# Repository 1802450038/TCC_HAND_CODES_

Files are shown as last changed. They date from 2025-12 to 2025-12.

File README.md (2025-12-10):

# Prótese Mioelétrica de Mão (TCC)

Este repositório contém os códigos fonte e documentação para o desenvolvimento de uma prótese de mão mioelétrica de baixo custo. O projeto combina modelagem 3D baseada em projetos open-source consagrados com um sistema de controle eletrônico customizado dividido em dois módulos via comunicação sem fio.

## 📋 Sobre o Projeto

O objetivo deste projeto é capturar sinais musculares (EMG) do usuário e transformá-los em movimentos precisos de abertura e fechamento da mão robótica. O sistema foi projetado para ser modular, separando a aquisição de dados do controle dos motores.

### Arquitetura do Sistema

O projeto é dividido em duas partes principais que se comunicam via protocolo **ESP-NOW**:

1. **EMG Box (Transmissor):** Responsável pela leitura dos sinais musculares e interface com o usuário.
2. **Controlador da Mão (Receptor):** Responsável por receber os comandos e acionar os servomotores da prótese.

## 🛠️ Hardware e Eletrônica

### 1. EMG Box (Processamento e Interface)

Este módulo é o "cérebro" de aquisição. Ele lê o sensor muscular, processa o sinal para decidir entre os estados de **Mão Aberta** ou **Mão Fechada** e envia o comando via WiFi.

* **Microcontrolador:** ESP32 DevKit V1
* **Funcionalidades:**
  * Leitura do sensor EMG.
  * **Menu Interativo:** Conta com um display OLED/LCD (verificar tipo no código) que permite ao usuário configurar parâmetros de sensibilidade e visualizar o status do sistema em tempo real.
  * Envio de pacotes via ESP-NOW.

### 2. Controlador da Mão (Atuadores)

Este módulo fica embarcado na própria estrutura da mão ou antebraço, recebendo os sinais e movendo os dedos.

* **Microcontrolador:** ESP32-C3 SuperMini (pelo seu tamanho reduzido e eficiência).
* **Funcionalidades:**
  * Recepção de comandos via ESP-NOW.
  * Controle PWM dos servomotores (via I2C ou direto, conforme implementação `esp32_i2cservo`).

### ⚡ Diagrama Elétrico

O esquema de ligação detalhado para ambos os módulos pode ser visualizado abaixo:

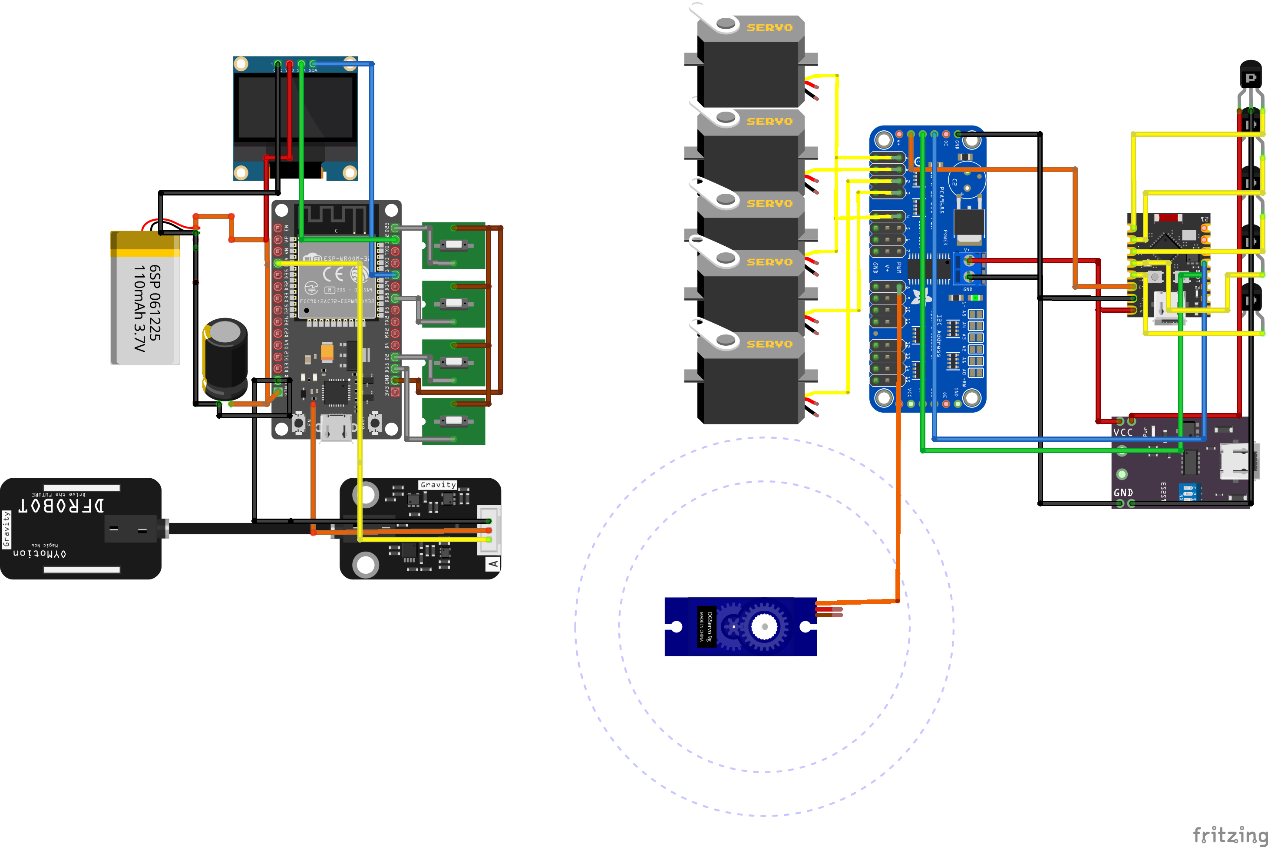
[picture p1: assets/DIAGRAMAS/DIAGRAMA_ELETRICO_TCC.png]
Diagrama Elétrico


## 🖨️ Design Mecânico e Peças 3D

A estrutura mecânica é uma hibridização de projetos renomados com adaptações personalizadas para acomodar a eletrônica e melhorar a funcionalidade.

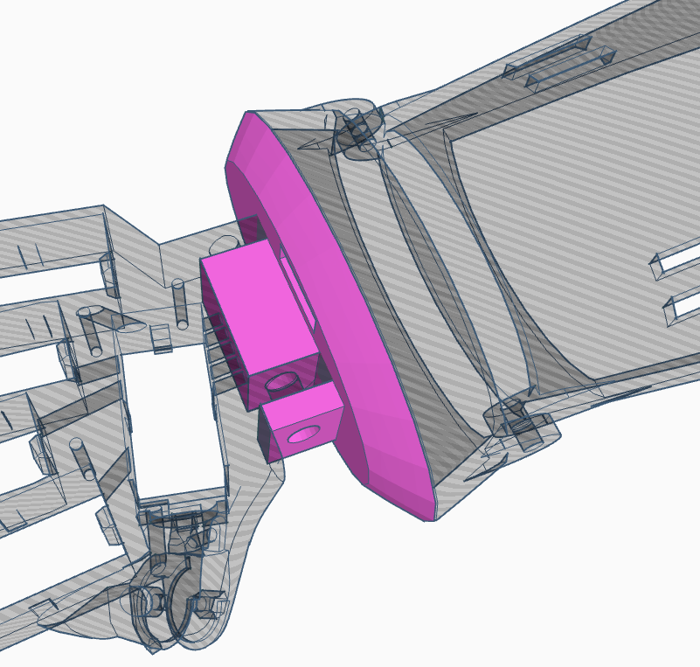
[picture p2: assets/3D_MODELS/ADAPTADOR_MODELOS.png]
Adaptador_modelos Adaptador Modelos


Ponteiras modificadas Ponteiras macias modificadasCaixa do sensor EMG Caixa sensor emg

### Referências Base

* **InMoov Hand:** A base do design dos dedos e palma. [Visite o projeto oficial](https://inmoov.fr/inmoov-hand/).
* **Capobussi Design:** Utilizado como referência para mecanismos e adaptações do antebraço. [Ver no Thingiverse](https://www.thingiverse.com/thing:3771283).

### 🌟 Peças Customizadas

Para tornar este projeto viável com o hardware escolhido (especialmente o ESP32-C3 SuperMini e o sistema de baterias), foram modeladas peças exclusivas:

* *Adaptador para união dos modelos 3D.*
* Ponteiras modifcadas para material flexivel.
* Caixa para acomodar o sensor emg juntamente do controlador, botões e tela.
* *As peças customizadas estão disponíveis na pasta `assets/3D_Models` deste repositório.*

## 📡 Comunicação (ESP-NOW)

A comunicação entre a **EMG Box** e a **Mão** utiliza o protocolo **ESP-NOW** da Espressif. Isso garante:

* Baixa latência (resposta rápida aos movimentos musculares).
* Conexão direta sem necessidade de roteador WiFi.
* Baixo consumo de energia.

O `EMG_BOX` atua como **Controller (Master)**, enviando a decisão de movimento, enquanto o `ESP32_C3` atua como **Peripheral (Slave)**, executando a ação motora.

## 🚀 Como Utilizar

1. **Upload dos Códigos:**
   * Carregue o código da pasta `EMG_BOX` no ESP32 DevKit V1.
   * Carregue o código da pasta ESP32_I2CServo no ESP32-C3 SuperMini.
   * *Nota: Certifique-se de atualizar o endereço MAC do receptor no código do transmissor.*
2. **Calibração:**
   * Ligue a EMG Box.
   * Utilize o **Menu no Display** para ajustar o limiar (threshold) do sensor EMG conforme a força muscular do usuário.
3. **Operação:**
   * Ao contrair o músculo, o sistema detectará o pico de sinal e enviará o comando de fechar/abrir a mão.

## 📂 Estrutura de Arquivos

```bash
├── EMG_BOX/              # Código fonte para o ESP32 DevKit V1
├── ESP32_I2CServo/         # Código fonte para o ESP32-C3 SuperMini
├── assets/3D_Models/            # Arquivos STL (Customizados e Modificados)
├── assets/DIAGRAMAS                 # Diagramas elétricos e documentação
└── README.md
```

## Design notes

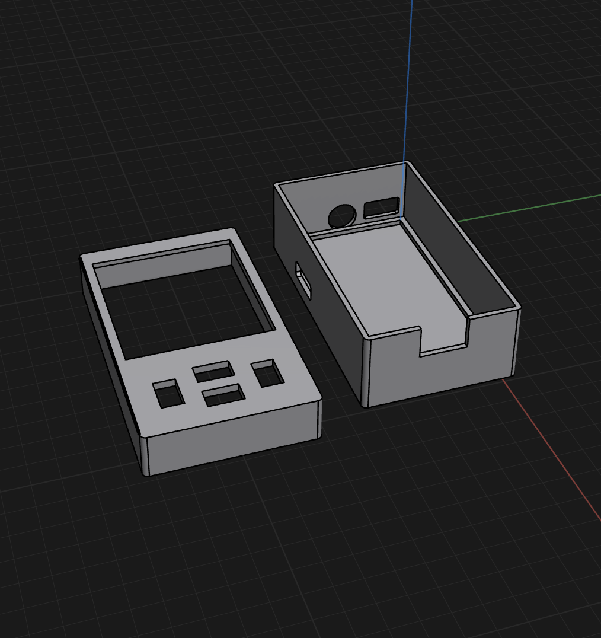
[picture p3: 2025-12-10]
assets/3D_MODELS/EMG_BOX.png

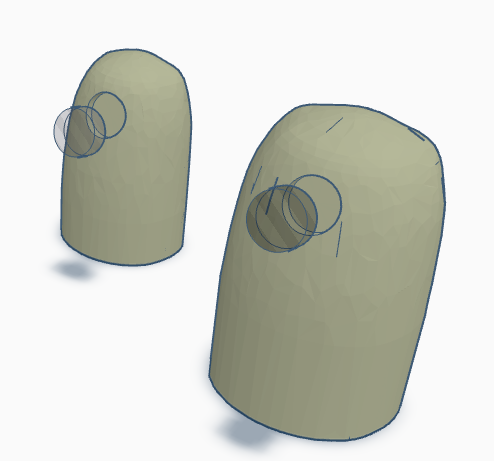
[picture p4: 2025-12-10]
assets/3D_MODELS/PONTEIRA_MODIFICADA.png

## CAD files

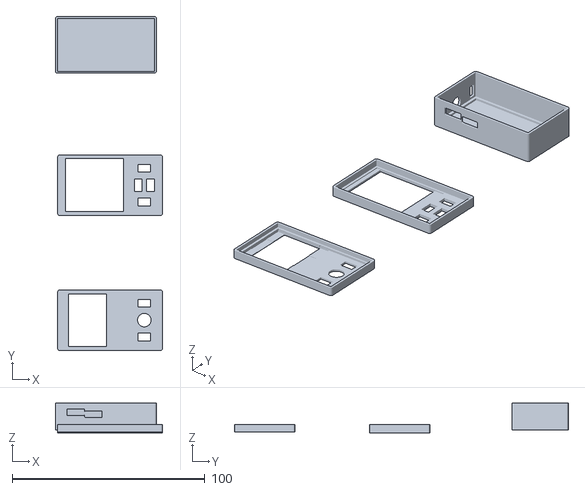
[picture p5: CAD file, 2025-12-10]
assets/3D_MODELS/EMG_BOX2mm.stl
55.6 x 173.2 x 15.5

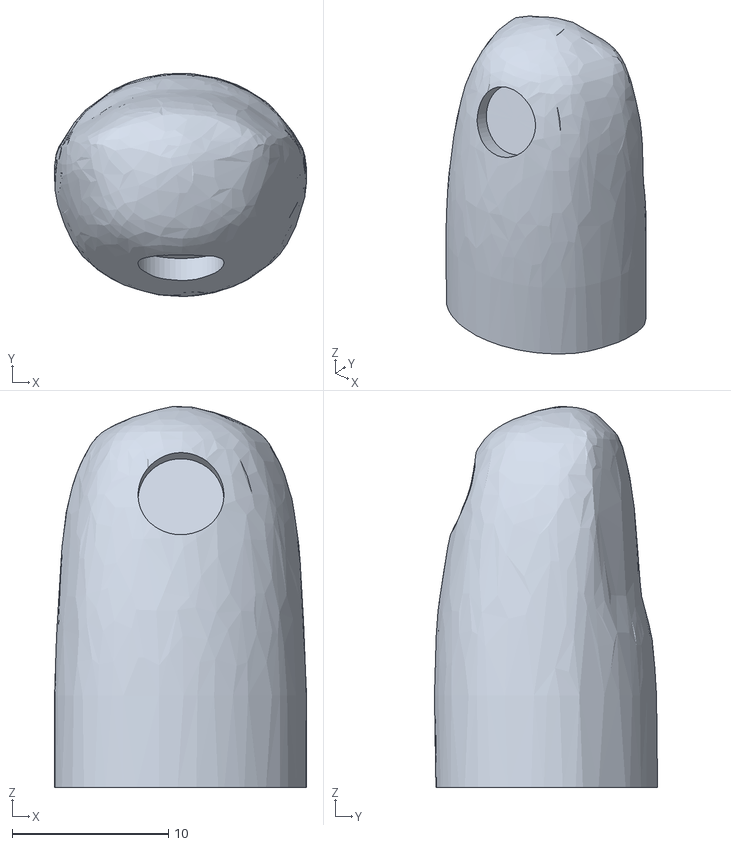
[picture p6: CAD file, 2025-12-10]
assets/3D_MODELS/TIP_THUMB.stl
16.1 x 14.3 x 24.4

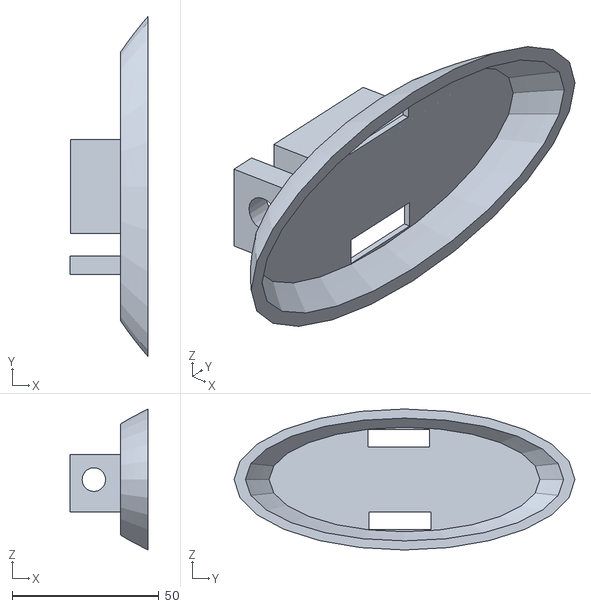
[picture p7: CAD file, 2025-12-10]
assets/3D_MODELS/JOINT_HAND.stl
26.7 x 116.0 x 48.0

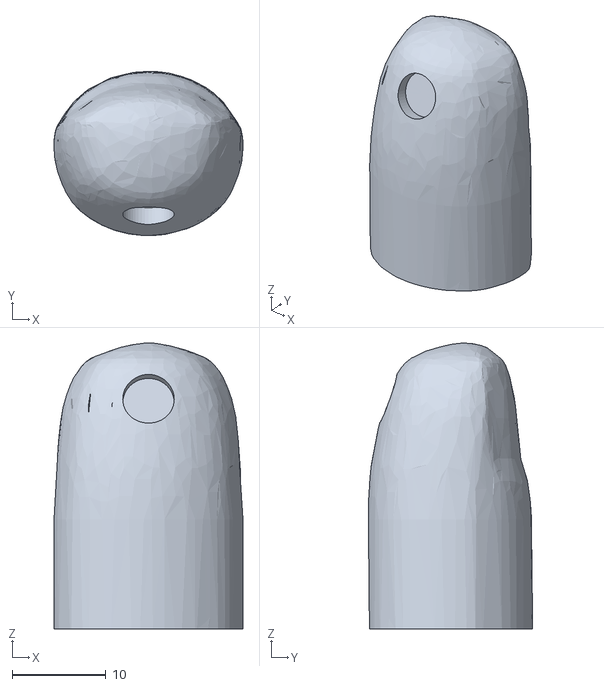
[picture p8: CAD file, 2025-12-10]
assets/3D_MODELS/TIP_FINGER.stl
20.2 x 17.6 x 30.6

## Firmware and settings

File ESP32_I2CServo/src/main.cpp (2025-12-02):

#include <Arduino.h>
#include <Wire.h>
#include "display.h"
#include "buttons.h"
#include "motors.h"
#include "hall.h"
#include <WiFi.h>
#include <esp_now.h>
#include <esp_wifi.h>
#include "smoothFilter.h" // Inclua a classe que criamos acima

#define OLED_ENABLE FALSE

// --- DEFINIÇÃO DOS PINOS E LIMITES ---
#define PIN_THUMB A4
#define PIN_INDEX A3
#define PIN_MIDDLE A2
#define PIN_RING A1
#define PIN_LITTLE A0

int THRESHOLD_THUMB = 2230;
int THRESHOLD_INDEX = 2320;
int THRESHOLD_MIDDLE = 0;
int THRESHOLD_RING = 2330;
int THRESHOLD_LITTLE = 2250;
// Instanciando os filtros (Apenas Pinos)
SmoothFilter filterThumb(PIN_THUMB);
SmoothFilter filterIndex(PIN_INDEX);
SmoothFilter filterMiddle(PIN_MIDDLE);
SmoothFilter filterRing(PIN_RING);
SmoothFilter filterLittle(PIN_LITTLE);

struct RawData
{
  int thumbVal;
  int indexVal;
  int middleVal;
  int ringVal;
  int littleVal;
};

RawData sharedData;          // Dados compartilhados
SemaphoreHandle_t dataMutex; // Cadeado de segurança

void readSensorsTask(void *parameter)
{
  for (;;)
  {
    // 1. Lê os valores suavizados (Isso leva alguns microssegundos)
    int t = filterThumb.read();
    int i = filterIndex.read();
    int m = filterMiddle.read();
    int r = filterRing.read();
    int l = filterLittle.read();

    // 2. Tenta pegar o cadeado para salvar na variável global
    if (xSemaphoreTake(dataMutex, (TickType_t)10) == pdTRUE)
    {
      sharedData.thumbVal = t;
      sharedData.indexVal = i;
      sharedData.middleVal = m;
      sharedData.ringVal = r;
      sharedData.littleVal = l;

      xSemaphoreGive(dataMutex); // Libera o cadeado IMEDIATAMENTE
    }

    // 3. Dorme por 10ms. Isso define a taxa de atualização (100Hz)
    // Essencial para o ESP32 não travar o Watchdog
    vTaskDelay(pdMS_TO_TICKS(10));
  }
}

int inc_thumb_pos = 0;
int inc_index_pos = 0;
int inc_middle_pos = 0;
int inc_ring_pos = 0;
int inc_little_pos = 0;
int inc_gesture = 0;
int inc_action_mode = 0;
bool inc_hand_state = false;
bool inc_feedback = false;
int inc_threshold_thumb = THRESHOLD_THUMB;
int inc_threshold_index = THRESHOLD_INDEX;
int inc_threshold_middle = THRESHOLD_MIDDLE;
int inc_threshold_ring = THRESHOLD_RING;
int inc_threshold_little = THRESHOLD_LITTLE;

typedef struct struct_inc_message
{
  int thumb_pos;
  int index_pos;
  int middle_pos;
  int ring_pos;
  int little_pos;
  int gesture;
  int action_mode;
  bool hand_state;
  bool feedback;
  int inc_threshold_thumb;
  int inc_threshold_index;
  int inc_threshold_middle;
  int inc_threshold_ring;
  int inc_threshold_little;
} struct_inc_message;

typedef struct struct_out_message
{
  int thumb_hall;
  int index_hall;
  int middle_hall;
  int ring_hall;
  int little_hall;
} struct_out_message;

String success;
struct_out_message OUT_DATA;
struct_inc_message INC_DATA;

esp_now_peer_info_t peerInfo;
uint8_t broadcastAddress[] = {0xe0, 0x5a, 0x1b, 0xa1, 0x33, 0x44};

void readMacAddress()
{
  uint8_t baseMac[6];
  esp_err_t ret = esp_wifi_get_mac(WIFI_IF_STA, baseMac);
  if (ret == ESP_OK)
  {
    Serial.printf("%02x:%02x:%02x:%02x:%02x:%02x\n",
                  baseMac[0], baseMac[1], baseMac[2],
                  baseMac[3], baseMac[4], baseMac[5]);
  }
  else
  {
    Serial.println("Failed to read MAC address");
  }
}
// Callback when data is sent
void OnDataSent(const uint8_t *mac_addr, esp_now_send_status_t status)
{
  Serial.print("\r\nLast Packet Send Status:\t");
  Serial.println(status == ESP_NOW_SEND_SUCCESS ? "Delivery Success" : "Delivery Fail");
  if (status == 0)
  {
    success = "Delivery Success :)";
  }
  else
  {
    success = "Delivery Fail :(";
  }
}
// Callback when data is received
void OnDataRecv(const uint8_t *mac, const uint8_t *incomingData, int len)
{
  memcpy(&INC_DATA, incomingData, sizeof(INC_DATA));
  inc_thumb_pos = INC_DATA.thumb_pos;
  inc_index_pos = INC_DATA.index_pos;
  inc_middle_pos = INC_DATA.middle_pos;
  inc_ring_pos = INC_DATA.ring_pos;
  inc_little_pos = INC_DATA.little_pos;
  inc_gesture = INC_DATA.gesture;
  inc_action_mode = INC_DATA.action_mode;
  inc_hand_state = INC_DATA.hand_state;
  inc_feedback = INC_DATA.feedback;
  inc_threshold_thumb = INC_DATA.inc_threshold_thumb;
  inc_threshold_index = INC_DATA.inc_threshold_index;
  inc_threshold_middle = INC_DATA.inc_threshold_middle;
  inc_threshold_ring = INC_DATA.inc_threshold_ring;
  inc_threshold_little = INC_DATA.inc_threshold_little;
}

void updateThresholds()
{
  THRESHOLD_THUMB = inc_threshold_thumb;
  THRESHOLD_INDEX = inc_threshold_index;
  THRESHOLD_MIDDLE = inc_threshold_middle;
  THRESHOLD_RING = inc_threshold_ring;
  THRESHOLD_LITTLE = inc_threshold_little;
}
// 1205 3425
void prepareDataToSend()
{
  OUT_DATA.thumb_hall = analogRead(HALL_SENSOR_PIN_THUMB);
  OUT_DATA.index_hall = analogRead(HALL_SENSOR_PIN_INDEX);
  OUT_DATA.middle_hall = analogRead(HALL_SENSOR_PIN_MIDDLE);
  OUT_DATA.ring_hall = analogRead(HALL_SENSOR_PIN_RING);
  OUT_DATA.little_hall = analogRead(HALL_SENSOR_PIN_LITTLE);
}

void setupNow()
{
  WiFi.mode(WIFI_STA);
  if (esp_now_init() != ESP_OK)
  {
    Serial.println("Error initializing ESP-NOW");
    return;
  }

  esp_now_register_recv_cb(esp_now_recv_cb_t(OnDataRecv));
}

void setup()
{
  // initServoFeedBack();

  initHallSensor();
  Serial.begin(115200); // Initialize serial communication
  delay(1000);
  Serial.println("Initializing");
  analogReadResolution(12);
  initPCA9685();
  // delay(500);
  // closeHand();
  delay(1000);
  openHand();
  delay(1000);
  Serial.println("Setup HALL");
  setupNow();
  dataMutex = xSemaphoreCreateMutex();
  xTaskCreate(
      readSensorsTask,
      "ReadSensors",
      4096,
      NULL,
      1,
      NULL);

  Serial.println("Sistema Iniciado com FreeRTOS Estavel.");
  delay(500);
}

bool isPressed(int val, int threshold)
{
  return (val < threshold);
}

void action_mode()
{
  switch (inc_action_mode)
  {
  case 0:
    Serial.println("Modo EMG");
    toogleHandState(inc_hand_state);
    break;
  case 1:
    Serial.println("Modo angulo");
    movServoByAngle(0, inc_thumb_pos);
    movServoByAngle(1, inc_index_pos);
    movServoByAngle(2, inc_middle_pos);
    movServoByAngle(3, inc_ring_pos);
    movServoByAngle(4, inc_little_pos);
    break;
  case 2:
    toggleGestureHand(inc_gesture);
    break;
  case 3:
    Serial.print("Modo Touch");

  case 4:
    Serial.print("Modo Toggle");
    toogleHandState(inc_hand_state);
  }
}

String getActionModeName(int action)
{
  if (action == 0)
  {
    return String("EMG - MODE");
  }
  else if (action == 1)
  {
    return String("ANGLE - MODE");
  }
  else if (action == 2)
  {
    return String("GESTURE - MODE");
  }
  else if (action == 3)
  {
    return String("TOGGLE - MODE");
  }
  else if (action == 4)
  {
    return String("DEBUG - MODE");
  }
  return "ERROR NOT DEFINED: " + String(action);
}

// // Display Functions
void updateValues(int freqMillis)
{
  static unsigned long lastSendTime = 0;

  if (millis() - lastSendTime >= freqMillis)
  {
    action_mode();
    // prepareDataToSend();
    updateThresholds();
    Serial.println("Thumb pos: " + String(inc_thumb_pos));
    Serial.println("Index pos: " + String(inc_index_pos));
    Serial.println("Middle pos: " + String(inc_middle_pos));
    Serial.println("Ring pos: " + String(inc_ring_pos));
    Serial.println("Little pos: " + String(inc_little_pos));
    Serial.println("Gesture : " + String(inc_gesture));
    Serial.println("Action mode: " + String(inc_action_mode) + " " + getActionModeName(inc_action_mode));
    Serial.println("Hand state: " + String(inc_hand_state));
    Serial.println("Feedback: " + String(inc_feedback));
    Serial.println("Thumb_threshold: " + String(THRESHOLD_THUMB));
    Serial.println("Index_threshold: " + String(THRESHOLD_INDEX));
    Serial.println("Middle_threshold: " + String(THRESHOLD_MIDDLE));
    Serial.println("Ring_threshold: " + String(THRESHOLD_RING));
    Serial.println("Little_threshold: " + String(THRESHOLD_LITTLE));
    lastSendTime = millis();
  }
}

void debugHallValues()
{
  Serial.print(OUT_DATA.thumb_hall);
  Serial.print(",");
  Serial.print(OUT_DATA.index_hall);
  Serial.print(",");
  Serial.print(OUT_DATA.middle_hall);
  Serial.print(",");
  Serial.print(OUT_DATA.ring_hall);
  Serial.print(",");
  Serial.println(OUT_DATA.little_hall);
}

void debugServo()
{
  for (size_t i = 0; i < 180; i++)
  {
    movServoByAngle(8, i);
    Serial.println("Angle: " + String(i));
    delay(300);
  }
}
void debugThresholds(bool validValues, RawData currentValues)
{
  if (validValues)
  {
    Serial.print("T:");
    Serial.print(":");
    Serial.print(THRESHOLD_THUMB);
    Serial.print(":");
    Serial.print(HALL_SENSOR_PIN_THUMB_THRESHOLD);
    Serial.print(":");
    Serial.print(currentValues.thumbVal);
    Serial.print(isPressed(currentValues.thumbVal, THRESHOLD_THUMB) ? "(ON) " : "(of) ");

    Serial.print("I:");
    Serial.print(currentValues.indexVal);
    Serial.print(isPressed(currentValues.indexVal, THRESHOLD_INDEX) ? "(ON) " : "(of) ");

    Serial.print("M:");
    Serial.print(currentValues.middleVal);
    Serial.print(isPressed(currentValues.middleVal, THRESHOLD_MIDDLE) ? "(ON) " : "(of) ");
    Serial.print("R:");
    Serial.print(currentValues.ringVal);
    Serial.print(isPressed(currentValues.ringVal, THRESHOLD_RING) ? "(ON) " : "(of) ");

    Serial.print("L:");
    Serial.print(currentValues.littleVal);
    Serial.println(isPressed(currentValues.littleVal, THRESHOLD_LITTLE) ? "(ON)" : "(of)");
  }
}

void loop()
{

  // readMacAddress();
  // debugServo();

  updateValues(300);

  RawData currentReads;
  bool dadosValidos = false;

  // // 1. Pega os dados da Task de forma segura
  if (xSemaphoreTake(dataMutex, (TickType_t)100) == pdTRUE)
  {
    currentReads = sharedData; // Copia rápida
    dadosValidos = true;
    xSemaphoreGive(dataMutex);
  }

  if (dadosValidos)
  {
    // debugThresholds(dadosValidos, currentReads);
    if (isPressed(currentReads.littleVal, THRESHOLD_LITTLE) || isPressed(currentReads.ringVal, THRESHOLD_RING) || isPressed(currentReads.indexVal, THRESHOLD_INDEX) || isPressed(currentReads.thumbVal, THRESHOLD_THUMB))
    {
      activeFeedBack(true);
    }
    else
    {
      activeFeedBack(false);
    }
  }
  else
  {
    Serial.println("Erro: Task ocupada ou travada!");
  }
}

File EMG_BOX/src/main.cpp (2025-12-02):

#include <Arduino.h>
#include <freertos/FreeRTOS.h>
#include <freertos/task.h>
#include <freertos/semphr.h>
#include "soc/soc.h"
#include "soc/rtc_cntl_reg.h"

// Inclua seus headers
#include "buttons.h"
#include "display.h"
#include "emg.h"
#include "hand.h"
#include "now.h"
#include "prefs.h"

// --- DEFINIÇÕES DE FREERTOS ---

// Handles para as tarefas
TaskHandle_t TaskSensorHandle = NULL;
TaskHandle_t TaskInterfaceHandle = NULL;

// Mutex para proteger variáveis globais compartilhadas
SemaphoreHandle_t xGlobalStateMutex;

// --- PROTÓTIPOS DAS TAREFAS ---
void TaskSensorLogic(void *pvParameters);
void TaskInterfaceComms(void *pvParameters);

void setup()
{
    WRITE_PERI_REG(RTC_CNTL_BROWN_OUT_REG, 0);
    Serial.begin(115200);

    // 1. Criação do Mutex antes de qualquer tarefa
    xGlobalStateMutex = xSemaphoreCreateMutex();

    // 2. Inicializações de Hardware (Single Threaded - Seguro fazer aqui)
    initDisplay();
    delay(1000);
    initButtons();
    delay(1000);
    initHand();
    delay(1000);
    initEMG(); // Calibrações iniciais
    delay(1000);
    initNow(); // Inicializa ESP-NOW

    // Opcional: Salvar configs iniciais se necessário (debug)
    // savePrefs();

    // 3. Criação das Tarefas

    // TAREFA 1: ALTA PRIORIDADE / TEMPO REAL (Core 1)
    // Responsável por: Ler EMG, Tratar Botões, Calcular Lógica da Mão
    xTaskCreatePinnedToCore(
        TaskSensorLogic,   // Função da tarefa
        "SensorLogic",     // Nome
        4096,              // Stack Size (memória)
        NULL,              // Parâmetros
        2,                 // Prioridade (2 = Alta)
        &TaskSensorHandle, // Handle
        1                  // Core ID (1 = App Core, padrão Arduino)
    );

    // TAREFA 2: BAIXA PRIORIDADE / I/O LENTO (Core 0)
    // Responsável por: Atualizar OLED, Enviar ESP-NOW
    xTaskCreatePinnedToCore(
        TaskInterfaceComms,   // Função da tarefa
        "InterfaceComms",     // Nome
        8192,                 // Stack Size (Display precisa de mais RAM)
        NULL,                 // Parâmetros
        1,                    // Prioridade (1 = Baixa)
        &TaskInterfaceHandle, // Handle
        0                     // Core ID (0 = Pro Core, junto com WiFi)
    );

    Serial.println("Sistema FreeRTOS Iniciado...");
}

void loop()
{
    // No FreeRTOS, o loop() padrão deve ficar vazio ou ser deletado.
    // A tarefa "Loop" do Arduino roda com prioridade 1 no Core 1.
    vTaskDelete(NULL); // Mata a tarefa loop padrão para economizar ciclos
}

// --- IMPLEMENTAÇÃO DAS TAREFAS ---

/* * TAREFA DE LÓGICA RÁPIDA (CORE 1)
 * Executa a cada 10ms (100Hz) ou mais rápido se necessário.
 * Foca em ler sensores e registrar inputs.
 */
void TaskSensorLogic(void *pvParameters)
{
    static unsigned long lastToggleTime = 0;
    bool inCooldown = false;
    static bool lastEmgActive = false;

    for (;;)
    {
        // 1. Atualizar Botões (OneButton precisa de tick frequente)
        // Protegemos com Mutex pois botões alteram ACTION_PAGE que o Display lê
        if (xSemaphoreTake(xGlobalStateMutex, (TickType_t)10) == pdTRUE)
        {
            btnTicks();
            xSemaphoreGive(xGlobalStateMutex);
        }

        // 2. Processar Lógica EMG (Leitura analógica e limites)
        // Nota: emgLines altera HAND_STATE e GESTURE
        // Podemos ler o analógico FORA do mutex (rápido), mas atualizar estados DENTRO

        // Pequena otimização: Ler analógico fora do bloqueio para não travar o Display
        int rawEmg = analogRead(ANALOG_EMG_1_PIN);
        //(Se você alterar emg.cpp para receber valor)

        if (xSemaphoreTake(xGlobalStateMutex, (TickType_t)10) == pdTRUE)
        {
            // A lógica atual de emgLines faz leitura e lógica juntas.
            // Idealmente refatore emgLines, mas por enquanto chamamos direto.

            // Exemplo: Atualiza lógica se estamos na página correta ou sempre
            // Você pode decidir se o EMG roda sempre ou só em certas páginas
            // Assumindo que roda sempre para manter o estado atualizado:
            if (ACTION_MODE == 0)
            {
                emgLines(rawEmg, false, TIME_OUT);
            }
            else if (ACTION_MODE == 4 || ACTION_MODE == 2)
            {
                unsigned long currentMillis = millis();

                if (inCooldown)
                {
                    unsigned long timePassed = currentMillis - lastToggleTime;

                    if (timePassed > EMG_TOGGLE_TIME)
                    {
                        inCooldown = false;
                        COOLDOWN_VAL = 0;
                    }
                    else
                    {
                        long remaining = EMG_TOGGLE_TIME - timePassed;
                        COOLDOWN_VAL = map(remaining, 0, EMG_TOGGLE_TIME, 0, 100);
                    }
                }
                else
                {
                    COOLDOWN_VAL = 0;
                }

                bool currentEmgActive = emgLinesReturn(rawEmg, TIME_OUT);

                if (!inCooldown)
                {

                    if (currentEmgActive && !lastEmgActive)
                    {
                        GESTURE += 1;
                        if (GESTURE > 5)
                        {
                            GESTURE = 0;
                        }
                        HAND_STATE = !HAND_STATE;
                        inCooldown = true;
                        lastToggleTime = currentMillis;
                        COOLDOWN_VAL = 100;
                    }
                }
                lastEmgActive = currentEmgActive;
            }
            else
            {
                inCooldown = false;
                COOLDOWN_VAL = 0;
            }
            xSemaphoreGive(xGlobalStateMutex);
        }
        Serial.println(HAND_STATE ? "Closed" : "Open");
        Serial.println(GESTURE);
        // Delay para permitir que o Watchdog do processador respire e definir a frequência
        vTaskDelay(pdMS_TO_TICKS(10)); // ~10ms delay (100 ticks por segundo para botões é ótimo)
    }
}
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

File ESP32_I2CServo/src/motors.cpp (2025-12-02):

#include <Adafruit_PWMServoDriver.h>
#include <ESP32Servo.h>
#include "motors.h"

Adafruit_PWMServoDriver pwm = Adafruit_PWMServoDriver();

Servo feedBackServo1;

bool handState = false; // Hand state

void initHand()
{
  movServoByAngle(0, 30);
  delay(500);
  movServoByAngle(1, 30);
  delay(500);
  movServoByAngle(2, 30);
  delay(500);
  movServoByAngle(3, 30);
  delay(500);
  movServoByAngle(4, 30);
  delay(500);
  movServoByAngle(0, 170);
  delay(500);
  movServoByAngle(1, 170);
  delay(500);
  movServoByAngle(2, 170);
  delay(500);
  movServoByAngle(3, 170);
  delay(500);
  movServoByAngle(4, 170);
  delay(500);
}

void initServoFeedBack()
{
  feedBackServo1.attach(FEED_1_BACK_PIN);
  feedBackServo1.write(STOP_FEEDBACK);
}

bool startPCATransmission()
{
  Serial.println("Verificando PCA9685...");

  // 1. Garante que o barramento I2C iniciou
  // (Se você já iniciou o Wire no initDisplay, não precisa desta linha, mas não faz mal)
  Wire.begin();

  // 2. Tenta comunicar com o endereço padrão 0x40
  Wire.beginTransmission(0x40);
  byte error = Wire.endTransmission();

  if (error == 0)
  {
    Serial.println("PCA9685 Encontrado! Inicializando PWM...");

    pwm.begin();
    pwm.setPWMFreq(SERVO_FREQ); // Defina SERVO_FREQ (ex: 50 ou 60)
    delay(10);                  // Pequeno delay para estabilizar
    return true;
  }
  else
  {
    Serial.print("ERRO: PCA9685 nao encontrado no endereco 0x40. Erro: ");
    Serial.println(error);
    return false;
  }
}

void initPCA9685()
{
  delay(1000);
  Serial.println("Initializing PCA9685 HERE");
  startPCATransmission();
  delay(1000);
}

void toggleHandStateOpen()
{
  handState = true;
}

void toggleHandStateClose()
{
  handState = false;
}

void movServoByAngle(int servo, int angle)
{
  int pulseLength = map(angle, 0, 180, SERVOMIN, SERVOMAX);
  // Serial.println("Pulse length: " + String(pulseLength) + " Angle: " + String(angle) + " Servo: " + String(servo));
  pwm.setPWM(servo, 0, pulseLength);
}

void activeFeedBack(bool state)
{
  if (state)
  {
    movServoByAngle(8, 170);
  }
  else
  {
    movServoByAngle(8, 100);
  }
}

void feedbackIntensity(int val)
{
  feedBackServo1.write(val);
}

void openHand()
{

  Serial.println("Opening hand");
  movServoByAngle(0, 175);
  movServoByAngle(1, 175);
  movServoByAngle(2, 175);
  movServoByAngle(3, 175);
  movServoByAngle(4, 175);
}

void closeHand()
{
  Serial.println("Closing hand");
  movServoByAngle(0, 20);
  movServoByAngle(1, 20);
  movServoByAngle(2, 20);
  movServoByAngle(3, 20);
  movServoByAngle(4, 20);
}

void toogleHandState(bool state)
{
  if (state)
  {
    closeHand();
  }
  else
  {
    openHand();
  }
}
void openFinger(int finger)
{
  // pwm.setPWM(finger, 0, SERVOMIN);
  movServoByAngle(finger, 180);
}

void closeFinger(int finger)
{
  // pwm.setPWM(finger, 0, SERVOMAX);
  movServoByAngle(finger, 0);
}

void openFingers(int *fingers)
{
  for (int i = 0; i < sizeof(fingers) / sizeof(fingers[0]); i++)
  {
    pwm.setPWM(fingers[i], 0, SERVOMIN);
  }
}

void closeFingers(int *fingers)
{
  for (int i = 0; i < sizeof(fingers) / sizeof(fingers[0]); i++)
  {
    pwm.setPWM(fingers[i], 0, SERVOMAX);
  }
}

void toggleGestureHand(int gesture)
{
  if (gesture == 0)
  {
    Serial.println("Gesture - OPEN");
    movServoByAngle(0, 180);
    openFinger(0);
    openFinger(1);
    openFinger(2);
    openFinger(3);
    openFinger(4);
  }
  else if (gesture == 1)
  {
    Serial.println("Gesture - ONE");
    movServoByAngle(0, 0);
    closeFinger(0);
    openFinger(1);
    closeFinger(2);
    closeFinger(3);
    closeFinger(4);
  }
  else if (gesture == 2)
  {
    Serial.println("Gesture - TWO");
    closeFinger(0);
    openFinger(1);
    openFinger(2);
    closeFinger(3);
    closeFinger(4);
  }
  else if (gesture == 3)
  {
    Serial.println("Gesture - THREE");
    closeFinger(0);
    openFinger(1);
    openFinger(2);
    openFinger(3);
    closeFinger(4);
  }
  else if (gesture == 4)
  {
    Serial.println("Gesture - OK");
    closeFinger(1);
    closeFinger(0);
    openFinger(2);
    openFinger(3);
    openFinger(4);
  }
  else if (gesture == 5)
  {
    Serial.println("Gesture - THUMB");
    openFinger(0);
    closeFinger(1);
    closeFinger(2);
    closeFinger(3);
    closeFinger(4);
  }
}

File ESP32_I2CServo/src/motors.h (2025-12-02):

#ifndef MOTORS_H
#define MOTORS_H

#include <Adafruit_PWMServoDriver.h>
#include <ESP32Servo.h>
#include "display.h"
// Servos Definitions
extern Adafruit_PWMServoDriver pwm;


extern bool handState; // Hand state
#define SERVOMIN 75 // Minimum pulse length count
#define SERVOMAX 500  // Maximum pulse length count
// ANALOG 50Hz
// DIGITAL 60Hz
#define SERVO_FREQ 50 // Servo frequency (60 Hz)
// Feedback Pins
#define FEED_1_BACK_PIN 21
#define STOP_FEEDBACK 82
#define MED_FEEDBACK 85
#define MAX_FEEDBACK 90

void initPCA9685();
void initHand();
void movServoByAngle(int servo, int angle);

void initServoFeedBack();
void activeFeedBack(bool state);
void openHand();
void closeHand();
void toogleHandState(bool state);
void openFinger(int finger);
void closeFinger(int finger);
void openFingers(int *fingers);
void closeFingers(int *fingers);
void checkHandState(bool enableServo);
void feedbackIntensity(int val);
void toggleGestureHand(int gesture);

#endif // MOTORS_H

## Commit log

2025-12-10 adicionando mais imagens
    [Diagrama_tcc_fr.fzz]
2025-12-10 adicionando detalhes
    [Diagrama_tcc_fr.fzz, EMG_BOX2mm.stl, JOINT_HAND.stl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]
